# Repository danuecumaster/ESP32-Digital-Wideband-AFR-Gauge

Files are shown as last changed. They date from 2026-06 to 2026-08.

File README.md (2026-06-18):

# ESP32 Digital Wideband AFR Gauge

### Compact standalone AFR display for 0-5V wideband controllers


[]()
[]()
[]()														 


[]()

---

## 📦 Overview

This project uses an **ESP32**, **ADS1115 16-bit ADC**, and **1.9" ST7789 TFT display** to create a compact digital AFR gauge for wideband controllers with a **0-5V analog output**.

Designed for automotive use, the gauge provides a large, easy-to-read AFR display with color-coded status indication and filtered ADC sampling for stable readings.

### Features

* ESP32-based design
* ADS1115 16-bit external ADC
* Compact 1.9" display
* Large monospace AFR readout
* Color-coded AFR status bar
* ADC calibration support
* Configurable ADC averaging
* RC-filtered 0-5V analog input interface
* Voltage divider input protection

---

## 📸 Hardware

### Display Board

[Ideaspark ESP32 LCD Board](https://manuals.plus/ae/1005007181435830)

### ADC

[ADS1115 16-bit I²C Analog-to-Digital Converter](https://www.ti.com/lit/ds/symlink/ads1115.pdf)

### Pinout and Circuit Diagram

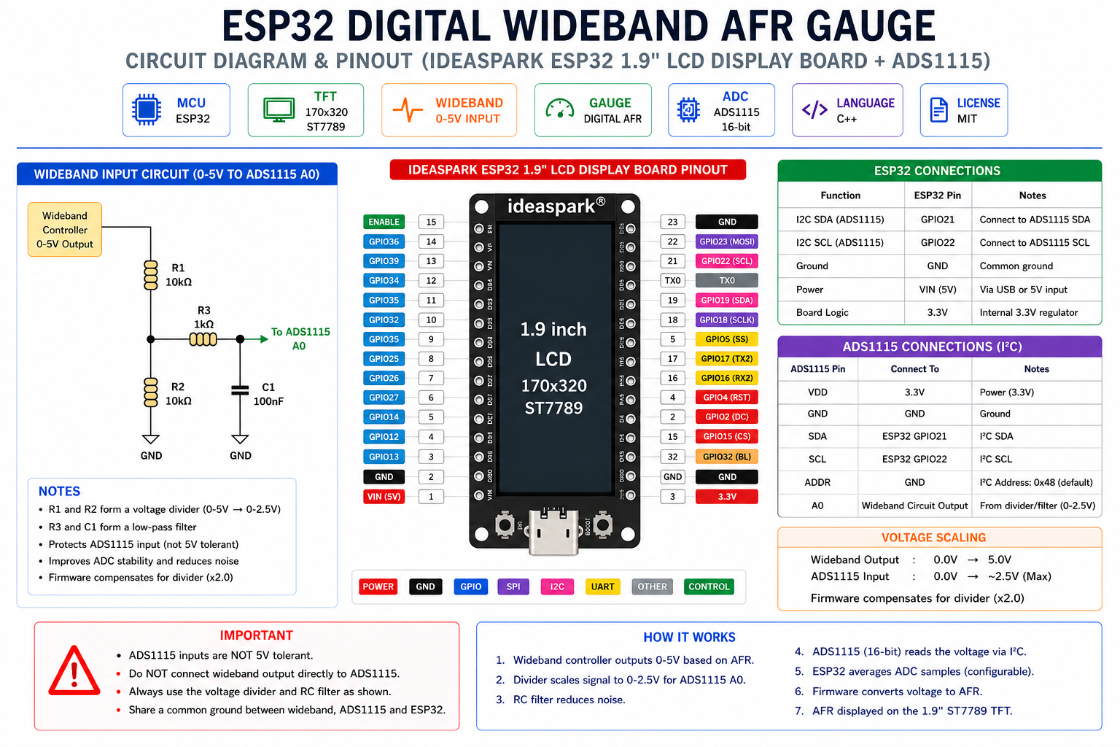
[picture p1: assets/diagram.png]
Ideaspark ESP32 Pinout


### Pin Assignment

| Function | GPIO |
| --- | --- |
| TFT MOSI | GPIO23 |
| TFT SCLK | GPIO18 |
| TFT CS | GPIO15 |
| TFT DC | GPIO2  |
| TFT RST | GPIO4  |
| TFT Backlight | GPIO32 |
| ADS1115 SDA | GPIO21 |
| ADS1115 SCL | GPIO22 |

Wideband input is connected to **ADS1115 channel A0**.

---

## ⚠️ Wideband Input Protection

### Divider Recommended for 0-5V Wideband Outputs

This project uses a 10kΩ / 10kΩ divider to reduce the wideband's 0-5V output to approximately 0-2.5V before it reaches the ADS1115.

The ADS1115 can measure input voltages up to its supply voltage (VCC). In this project, the ADS1115 is powered from the ESP32's 3.3V supply to ensure safe compatibility with the ESP32's 3.3V I²C bus.

Because the wideband output can reach 5V, the divider reduces the signal to a safe measurement range while also matching the firmware's scaling assumptions.

The divider also provides additional protection against accidental overvoltage conditions.

### Recommended Input Circuit

```text
Wideband 0-5V
     |
    10k
     |
     +---- 1k ----+----> ADS1115 A0
     |            |
    10k         100nF
     |            |
    GND          GND
```

### Required Components

| Component | Quantity | Notes |
| --- | --- | --- |
| 10kΩ resistor | 2 | 1% metal film recommended |
| 1kΩ resistor | 1 | 1%-5% metal film |
| 100nF capacitor | 1 | Ceramic, ≥16V |

### How It Works

* 10kΩ / 10kΩ divider reduces 0-5V to approximately 0-2.5V
* 1kΩ + 100nF create a low-pass filter
* ADS1115 measures the filtered signal on channel A0
* Firmware compensates for the divider ratio
* ESP32 communicates with the ADS1115 over I²C

### ADC Scaling

```text
Wideband Output : 0.0V → 5.0V
ADS1115 Input   : 0.0V → 2.5V
```

---

## 🔤 Display Font

This project uses a custom **JetBrains Mono Bold 50pt** font.

Required file:

* [JetBrainsMonoBold50pt7b.h](https://raw.githubusercontent.com/danuecumaster/ESP32-Digital-Wideband-AFR-Gauge/main/assets/JetBrainsMonoBold50pt7b.h)

Place the file in the project directory before compiling.

---

## 📏 AFR Calibration

Current firmware assumes:

```text
0.0V → 10.00 AFR
5.0V → 20.00 AFR
```

Current conversion formula:

```cpp
float voltage	= ((rawV + ADC_OFFSET) * V_MULTIPLIER * ADC_CORRECTION);
float afr 		= (AFR_MIN + (voltage * WBO_MULTIPLIER));
												   
```

Where:

```text
rawV            = ADS1115 measured voltage (after divider)
V_MULTIPLIER    = Divider compensation factor (2.0)
ADC_OFFSET      = ADC offset correction
ADC_CORRECTION  = ADC gain correction factor
WBO_MULTIPLIER  = AFR scaling factor
```

If your wideband controller uses a different voltage-to-AFR mapping, adjust the conversion formula accordingly.

---

## 🎯 ADC Calibration

The ADS1115 is generally very accurate, but resistor tolerances in the divider network may introduce small measurement errors.

For maximum accuracy, the firmware includes both a gain correction factor and an offset correction:

```cpp
#define ADC_CORRECTION 1.0000f
#define ADC_OFFSET     0.0000f
```

Voltage calculation:

```cpp
float voltage = ((rawV + ADC_OFFSET) * V_MULTIPLIER * ADC_CORRECTION);
```

### Calibration Parameters

```text
ADC_OFFSET     = Corrects zero-voltage offset error
ADC_CORRECTION = Corrects gain (scaling) error
```

---

### Step 1 - Offset Calibration

Disconnect the wideband signal or apply a known 0.0V input.

Observe the voltage reported by the firmware:

```text
Firmware Voltage : 0.004V
Actual Voltage   : 0.000V
```

Calculate:

```text
ADC_OFFSET = Actual Voltage - Firmware Voltage
ADC_OFFSET = 0.000 - 0.004
ADC_OFFSET = -0.004
```

Update the firmware:

```cpp
#define ADC_OFFSET -0.0040f
```

The reported voltage should now read approximately 0.000V.

---

### Step 2 - Gain Calibration

Apply a known voltage near the upper end of the operating range.

Example:

```text
Wideband Input Voltage  : 2.500V
Firmware Voltage   		: 2.450V
```

Calculate:

```text
ADC_CORRECTION = Actual Voltage / Firmware Voltage
ADC_CORRECTION = 2.500 / 2.450
ADC_CORRECTION = 1.0204
```

Update the firmware:

```cpp
#define ADC_CORRECTION 1.0204f
```

---

### Verification

After setting both parameters, verify several points across the operating range:

Recommended wideband input test points:
```text
0.0V
1.5V
3.0V
5.0V
```

If the calculated voltage closely matches the multimeter reading at all test points, calibration is complete.

---

### Notes

* Perform offset calibration before gain calibration.
* ADC_OFFSET corrects zero-voltage errors.
* ADC_CORRECTION corrects scaling errors.
* Most installations require little or no adjustment.
* Calibration only needs to be performed once unless hardware is changed.
* The 100nF filter capacitor does not affect DC calibration accuracy.

---

## 📊 ADC Filtering

The ADS1115 reading can be averaged in firmware:

```cpp
#define ADC_SAMPLES 4
```

Current firmware averages the configured number of ADS1115 samples before calculating AFR.

Combined with the 1kΩ + 100nF RC filter, this provides stable AFR readings while maintaining good response time.

Increase `ADC_SAMPLES` for smoother readings or decrease it for faster response.

---

## 🧰 Hardware Used

* [Ideaspark ESP32 1.9" LCD Board](https://manuals.plus/ae/1005007181435830)
* [ADS1115 16-bit I²C ADC Module](https://www.ti.com/lit/ds/symlink/ads1115.pdf)
* Wideband Controller with 0-5V Analog Output [Example:14Point7 SLC 2](https://www.14point7.com/products/sigma-lambda-controller-free-2)
* 10kΩ Resistors (×2)
* 1kΩ Resistor
* 100nF Ceramic Capacitor

---

## 📥 Installation

1. Download or clone the repository
2. Download `JetBrainsMonoBold50pt7b.h` and copy to main directory
3. Open the project in Arduino IDE
4. Install required libraries:

   * Adafruit GFX
   * Adafruit ST7789
   * Adafruit ADS1X15
5. Assemble the divider and filter circuit
6. Connect ADS1115 to the ESP32 via I²C
7. Connect the wideband analog output
8. Upload the firmware
9. Power the ESP32
10. Enjoy your new AFR gauge 🚗

---

## ❓ FAQ

### Why is the AFR reading unstable?

Verify:

* The 1kΩ + 100nF filter is installed
* Wideband ground and ESP32 ground are connected together
* ADS1115 ground is connected to the same ground reference
* Wiring is kept reasonably short

### Can I connect a 5V signal directly to ADS1115 A0?

Not in this project.

The firmware assumes the recommended 10kΩ / 10kΩ divider network, which reduces the signal to approximately 0-2.5V before it reaches the ADS1115.

### Why does the displayed AFR not match my controller?

Different wideband controllers may use different voltage-to-AFR mappings.

Adjust the conversion formula in the firmware to match your controller's output specification.

### Want faster or slower display updates?

```cpp
#define FRAME_TIME_MS 50
```

Examples:

```text
100 = 10 FPS
50  = 20 FPS
33  = 30 FPS
```

---

## 📜 License

MIT License

---

## ❤️ Credits

Built for enthusiasts who prefer gauges that are simple, readable, and purpose-built.

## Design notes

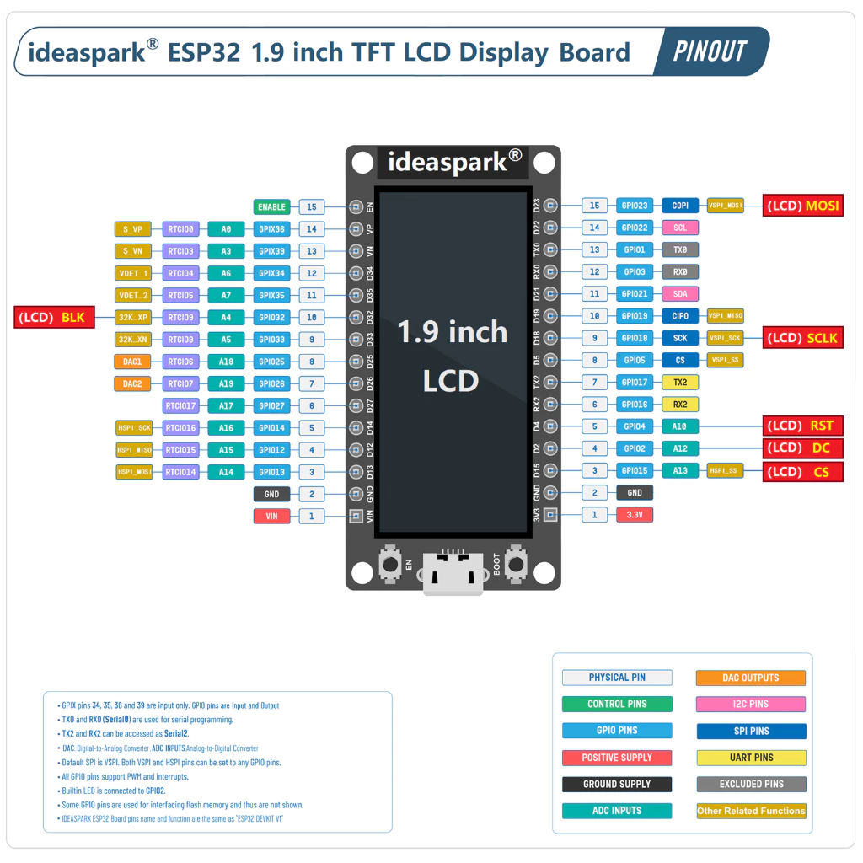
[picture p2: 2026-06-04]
assets/pinout.jpg

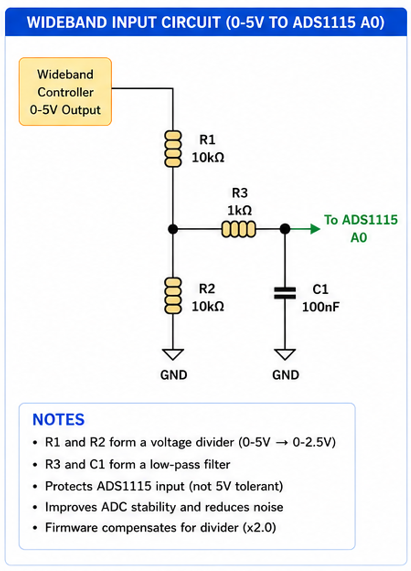
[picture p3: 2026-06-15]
assets/voltage-divider-circuit.png

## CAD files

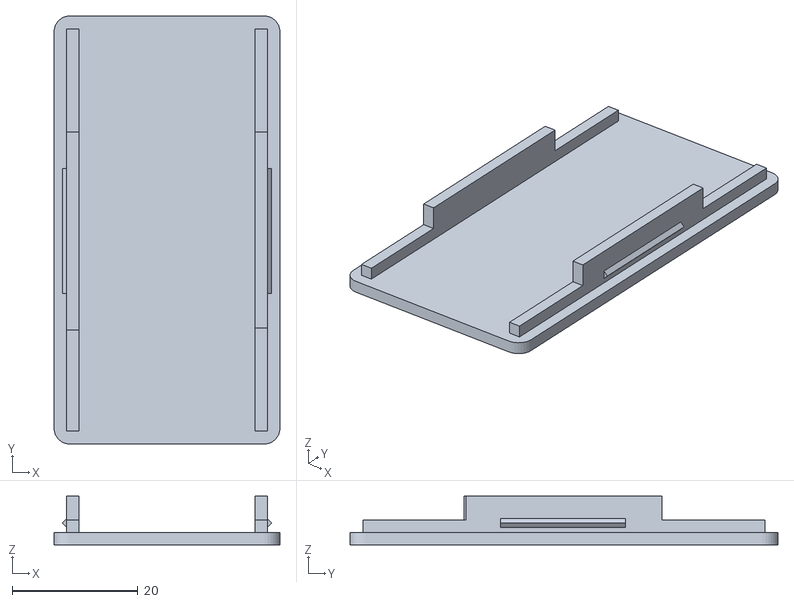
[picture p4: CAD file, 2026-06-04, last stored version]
assets/cover.stl
36.0 x 68.2 x 7.80

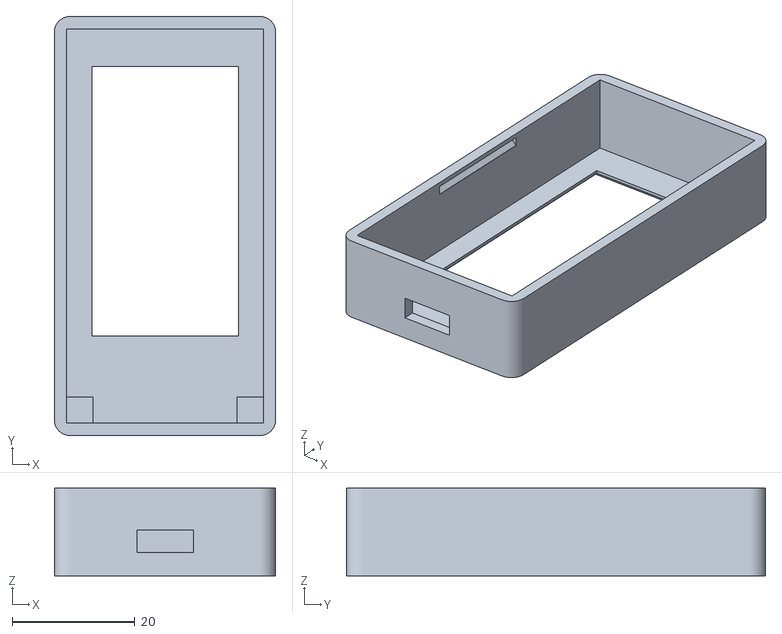
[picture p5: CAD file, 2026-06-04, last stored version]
assets/case.stl
36.0 x 68.2 x 14.3

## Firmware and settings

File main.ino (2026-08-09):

// -----------------------------------------------------------------------------
//   WB 0-5V
//      |
//     10K
//      |
//      +---- 1K ----+----> ADS1115 A0 ----> ESP32 I2C
//      |            |		  |				 
//     10K         100NF      | 			 
//      |            |		  |				 
//     GND          GND		 GND			
//
// DIVIDER: 10K / 10K  -> 0-5V BECOMES APPROXIMATELY 0-2.5V
// FILTER : 1K + 100NF -> REDUCES ADC NOISE
//
// SEE README.MD FOR WIRING DETAILS.
// -----------------------------------------------------------------------------

/**** LIBRARIES ****/
#include <Adafruit_GFX.h>
#include <Adafruit_ST7789.h>
#include <SPI.h>
#include <Wire.h>
#include <Adafruit_ADS1X15.h>
#include "JetBrainsMonoBold50pt7b.h"
/**** LIBRARIES ****/

/**** DISPLAY PINS ****/
#define TFT_MOSI  		23
#define TFT_SCLK  		18
#define TFT_CS    		15
#define TFT_DC    		2
#define TFT_RST   		4
#define BL        		32
/**** DISPLAY PINS ****/

/**** I2C PINS ****/
#define SDA_PIN   		21
#define SCL_PIN   		22
/**** I2C PINS ****/

/**** DISPLAY SETTINGS ****/
#define SCREEN_W	 	320
#define SCREEN_H	 	170
#define FRAME_TIME_MS 	50 				// 100 = 10FPS, 50 = 20FPS, 33 = 30FPS
/**** DISPLAY SETTINGS ****/

/**** ADC SETTINGS ****/
#define ADC_SAMPLES		4				// NUMBER OF ADC SAMPLES
#define ADC_CORRECTION	1.0000f			// ADC LINEAR CALIBRATION FACTOR
#define ADC_OFFSET		-0.0000f		// ADC OFFSET VOLTAGE +-
#define V_MULTIPLIER	2.0f			// COMPENSATE FOR 10K/10K DIVIDER
#define WBO_MULTIPLIER	2.0f			// WBO CONTROLLER MULTIPLIER 
#define AFR_TOLERANCE	0.5f			// ERROR THRESHOLD
/**** ADC SETTINGS ****/

/**** AFR BOX SETTINGS ****/
#define BG_COLOR  		0x0841
#define TXT_COLOR 		ST77XX_WHITE
#define AFR_MIN		 	10.0f
#define AFR_MAX		 	20.0f
#define AFR_RICH	 	12.0f
#define AFR_STOICH	 	15.0f
#define NUM_BOXES 		11
#define GAP 			2
#define BOX_HEIGHT 		28
#define INACTIVE_COLOR  0x0861
/**** AFR BOX SETTINGS ****/

/**** DEBUG ****/
#define DEBUG_MODE  	1 				// 1 = ON, 0 = OFF
/**** DEBUG ****/

Adafruit_ST7789 tft(TFT_CS, TFT_DC, TFT_RST);
GFXcanvas16 canvas(SCREEN_W, SCREEN_H);

Adafruit_ADS1115 ads;

int textX;
int textY;
char buf[10];

void drawTopBoxes(GFXcanvas16 &c, float afr) {	
    int activeBoxes;
	uint16_t activeColor;

	if (afr < (AFR_MIN - AFR_TOLERANCE)) {
        activeBoxes = 0;
	} else {
		activeBoxes = min(NUM_BOXES, (int)ceilf(afr - (AFR_MIN - 1.0f)));
	}
	
	if (afr < AFR_RICH) {
		activeColor = ST77XX_BLUE;
	} else if (afr < AFR_STOICH) {
		activeColor = ST77XX_GREEN;
	} else {
		activeColor = ST77XX_RED;
	}

    for (int i = 0; i < NUM_BOXES; i++) {                
        int x1 = (SCREEN_W * i) / NUM_BOXES;
        int x2 = (SCREEN_W * (i + 1)) / NUM_BOXES;

        x1 += GAP / 2;
        x2 -= GAP / 2;
        int w = x2 - x1;

        c.fillRoundRect( x1, 4, w, BOX_HEIGHT, 4, (i < activeBoxes) ? activeColor : INACTIVE_COLOR );
    }
}

void setup() {
    Serial.begin(115200);

    tft.init(SCREEN_H, SCREEN_W);
    tft.setRotation(3);
    tft.fillScreen(BG_COLOR);

    pinMode(BL, OUTPUT);
    digitalWrite(BL, HIGH);

    canvas.setFont(&JetBrainsMono_Bold50pt7b);
    canvas.setTextColor(TXT_COLOR);

    int16_t x1, y1;
    uint16_t w, h;
    canvas.getTextBounds("00.00", 0, 0, &x1, &y1, &w, &h);

    textX = (SCREEN_W - w) / 2 - x1;
    textY = ((SCREEN_H - 36) - h) / 2 - y1 + 36;
	
	Wire.begin(SDA_PIN, SCL_PIN);
	Wire.setClock(400000);
	if (!ads.begin()) {
        Serial.println("ADS1115 not found");
        while (1);
    }
	ads.setGain(GAIN_ONE);
	Serial.println("ADS1115 initialized");
}

void loop() {  
	uint32_t startLoop	= millis();	
	float sum 			= 0.0f;
	float afr			= 0.0f;
	
	for (int i = 0; i < ADC_SAMPLES; i++) {
		int16_t adc = ads.readADC_SingleEnded(0);
        sum += ads.computeVolts(adc);
    }
	
    float rawV			= ((float)sum / ADC_SAMPLES);
	float voltage		= ((rawV + ADC_OFFSET) * V_MULTIPLIER * ADC_CORRECTION);
	afr					= (AFR_MIN + (voltage * WBO_MULTIPLIER));
	
	#if DEBUG_MODE
		Serial.printf("ADC=%.6f WB=%.4fV AFR=%.2f\n", rawV, voltage, afr);
	#endif
	
	if(afr < (AFR_MIN - AFR_TOLERANCE) || afr > (AFR_MAX + AFR_TOLERANCE)) {
		strcpy(buf, "ERROR");
		afr = 0.0f;
	} else {
		snprintf(buf, sizeof(buf), "%.2f", afr);			
	}
	canvas.fillScreen(BG_COLOR);
	drawTopBoxes(canvas, afr);
	canvas.setCursor(textX, textY);
	canvas.print(buf);
	tft.drawRGBBitmap(0, 0, canvas.getBuffer(), SCREEN_W, SCREEN_H);	

	uint32_t endLoop = (millis() - startLoop);
    if (endLoop < FRAME_TIME_MS) {
		delay(FRAME_TIME_MS - endLoop);
	}	
}

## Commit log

2026-06-09 Create voltage-divider-circuit.png
    Voltage divider circuit
2026-06-15 updated diagrams due to ADS1115
    [case.stl, cover.stl]
2026-08-09 Adjust active box calculation for AFR tolerance
    [main.ino]
